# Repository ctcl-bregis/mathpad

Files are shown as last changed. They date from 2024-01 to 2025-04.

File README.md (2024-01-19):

# MathPad "Fort Myers"

MathPad was an idea to recreate HP's CalcPad device with modern components and design. The codename "Fort Myers" was chosen because the entire project was designed during the business trip to the Fort Myers area for work in Fort Myers Beach. The device was developed with the idea of that it would be used with the Xactimate estimating software.

The project was the first of CTCL's circuit design projects to reach the assembly stage; PCB and components ordered and received.

The project was likely abandoned in December 2022 due to the lack of equipment and skills required to solder the tiny, delicate components. The project was officially canceled on January 19, 2024 after the introduction of an off-the-shelf product, the Logitech G600 MMO mouse into my workflow in January 2023. This project was made with the idea of necessity as I was expected to start having to use Xactimate after the conclusion of the business trip.

On January 19, 2024, I released whatever work I had done for the project. The existing components ordered may be reused for other projects.

## Files
Included in the "hw" directory is all of the hardware files exported from EasyEDA.

No firmware has been developed for the device

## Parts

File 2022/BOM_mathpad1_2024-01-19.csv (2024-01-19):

ID | Name | Designator | Footprint | Quantity | Manufacturer Part | Manufacturer | Supplier | Supplier Part | Price
1 | 1uF | C1,C4,C5,C6,C7 | C0603 | 5 | CL10B105KO8NNNC | Samsung Electro-Mechanics | LCSC | C59782 | 0.004
2 | 4.7uF | C2,C3,C9 | C1206 | 3 | CL31B475KBHNNNE | Samsung Electro-Mechanics | LCSC | C51205 | 0.032
3 | 100nF | C8,C10,C11,C12,C13,C14,C15,C16 | C0603 | 8 | CL10B104KB8NNNC | Samsung Electro-Mechanics | LCSC | C1591 | 0.003
4 | 1N4148TR-C84412 | D1,D2,D3,D4,D5,D6,D7,D8,D9,D10,D11,D12,D13,D14,D15,D16,D17,D18,D19,D20,D21,D22,D23,D24,D25,D26,D27,D28,D29 | DO-35_BD2.0-L4.2-P8.20-D0.5-RD | 29 | 1N4148TR | Vishay | LCSC | C84412 | 0.022
5 | 0.5K-AX-31PWB | FPC1 | FPC-SMD_31P-P0.50_HDGC_0.5K-AX-31PWB | 1 | 0.5K-AX-31PWB | HDGC | LCSC | C2911949 | 0.156
6 | DZ254R-11-03-63 | H1 | HDR-TH_3P-P2.54-V-M | 1 | DZ254R-11-03-63 | Dealon | LCSC | C2935909 | 0.017
8 | 10uH | L1 | IND-SMD_L5.0-W5.0_LQH5BPBXX | 1 | LQH5BPB100MT0L | Murata Electronics | LCSC | C521243 | 0.256
9 | 1M | R1 | R0603 | 1 | RC0603JR-071ML | YAGEO | LCSC | C107698 | 0.001
10 | 68K | R2 | R0603 | 1 | RC0603JR-0768KL | YAGEO | LCSC | C113301 | 0.001
11 | 910K | R3 | R0603 | 1 | RC0603JR-07910KL | YAGEO | LCSC | C141274 | 0.001
12 | 0 | R4,R5 | R0603 | 2 | RC0603JR-070RL | YAGEO | LCSC | C95177 | 0.001
13 | CPG151101D93 | SW1,SW2,SW3,SW4,SW5,SW6,SW7,SW8,SW9,SW10,SW11,SW12,SW13,SW14,SW15,SW16,SW17,SW18,SW19,SW20,SW21,SW22,SW23,SW24,SW25,SW26,SW27,SW28,SW29 | SW-TH_CPG151101D9X | 29 | CPG151101D93 | Kailh | LCSC | C400237 | 0.248
14 | RT9078-33GJ5 | U1,U5 | TSOT-23-5_L2.9-W1.6-P0.95-LS2.8-BR | 2 | RT9078-33GJ5 | Richtek Tech | LCSC | C110427 | 0.09
15 | STM32G0B1RCT6 | U2 | LQFP-64_L10.0-W10.0-P0.50-LS12.0-BL | 1 | STM32G0B1RCT6 | STMicroelectronics | LCSC | C3034735 | 3.834
16 | TLV61046ADBVR | U3 | SOT-23-6_L2.9-W1.6-P0.95-LS2.8-BL | 1 | TLV61046ADBVR | Texas Instruments | LCSC | C464815 | 0.423
17 | U241-041N-1BR85-1 | USB1 | USB-B-TH_U241-041N-1BR85-1 | 1 | U241-041N-1BR85-1 | XKB Enterprise | LCSC | C397338 | 0.129
18 | 8MHz | X1 | OSC-SMD_3P-L3.2-W1.3-P1.2-L | 1 | CSTNE8M00G55A000R0 | Murata Electronics | LCSC | C341523 | 0.208

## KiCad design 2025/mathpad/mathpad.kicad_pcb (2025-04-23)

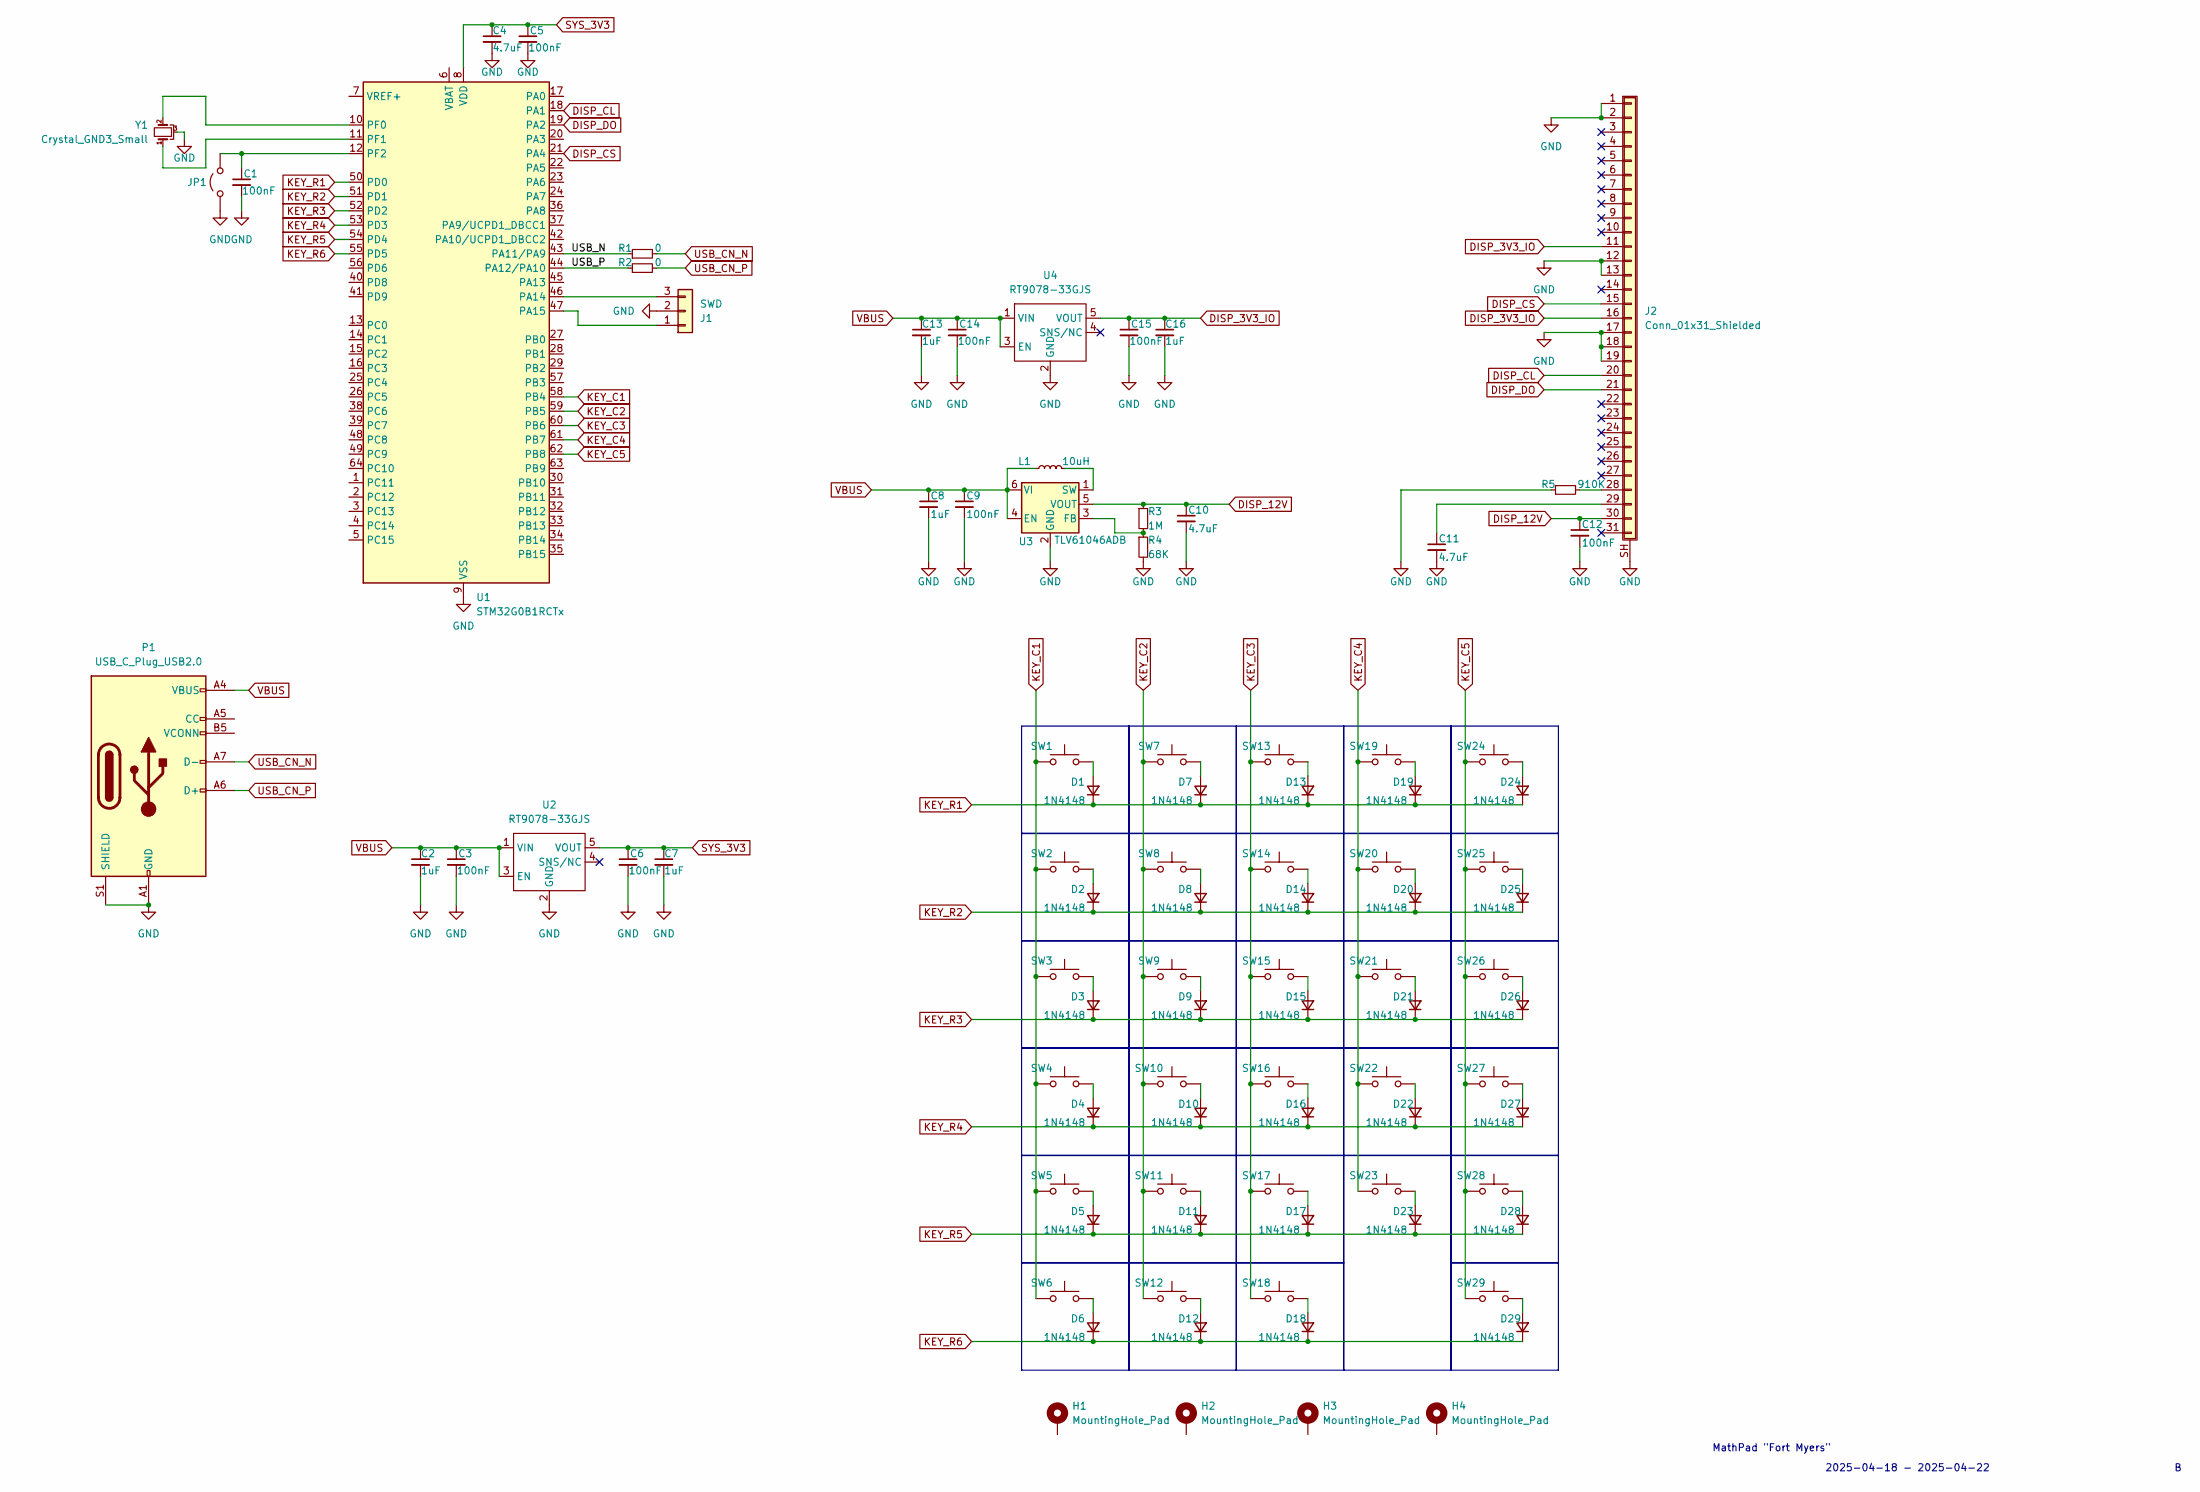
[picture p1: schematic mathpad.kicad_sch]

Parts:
C1, C3, C5, C6, C9, C12, C14, C15: 100nF; C_0603_1608Metric
C2, C7, C8, C13, C16: 1uF; C_0603_1608Metric
C4, C10, C11: 4.7uF; C_1206_3216Metric
D1, D2, D3, D4, D5, D6, D7, D8, D9, D10, D11, D12, D13, D14, D15, D16, D17, D18, D19, D20, D21, D22, D23, D24, D25, D26, D27, D28, D29: 1N4148; D_DO-35_SOD27_P7.62mm_Horizontal
H1, H2, H3, H4: MountingHole_Pad; MountingHole_2.2mm_M2_Pad
J1: SWD; PinHeader_1x03_P2.54mm_Vertical
J2: Conn_01x31_Shielded; TE_3-1734839-1_1x31-1MP_P0.5mm_Horizontal
JP1: Jumper_2_Open; SolderJumper-2_P1.3mm_Open_Pad1.0x1.5mm
L1: 10uH; L_Taiyo-Yuden_MD-5050
P1: USB_C_Plug_USB2.0; USB_C_Receptacle_G-Switch_GT-USB-7010ASV
R1, R2: 0; R_0603_1608Metric
R3: 1M; R_0603_1608Metric
R4: 68K; R_0603_1608Metric
R5: 910K; R_0603_1608Metric
SW1, SW2, SW3, SW4, SW5, SW6, SW7, SW8, SW9, SW10, SW11, SW12, SW13, SW14, SW15, SW16, SW17, SW18, SW19, SW20, SW21, SW22, SW23, SW24, SW25, SW26, SW27, SW28, SW29: SW_Push; SW_Cherry_MX_1.00u_PCB
U1: STM32G0B1RCTx; LQFP-64_10x10mm_P0.5mm
U2, U4: RT9078-33GJS; TSOT-23-5
U3: TLV61046ADB; SOT-23-6
Y1: Crystal_GND3_Small; Resonator_SMD_Murata_CSTCR_4.5x2x1.15mm

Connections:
/USB_N: R1.1, U1.43 (PA11/PA9)
/USB_P: R2.1, U1.44 (PA12/PA10)
DISP_3V3_IO: C15.1, C16.1, J2.11, J2.16, U4.5 (VOUT)
DISP_12V: C10.1, C12.1, J2.30, R3.1, U3.5 (VOUT)
DISP_CL: J2.20, U1.18 (PA1)
DISP_CS: J2.15, U1.21 (PA4)
DISP_DO: J2.21, U1.19 (PA2)
GND: C1.2, C2.2, C3.2, C4.2, C5.2, C6.2, C7.2, C8.2, C9.2, C10.2, C11.2, C12.2, C13.2, C14.2, C15.2, C16.2, J1.2, J2.1, J2.2, J2.12, J2.13, J2.17, J2.18, J2.19, J2.SH (Shield), JP1.2 (B), P1.A1 (GND), P1.A12 (GND), P1.B1 (GND), P1.B12 (GND), P1.S1 (SHIELD), R4.2, R5.1, U1.9 (VSS), U2.2 (GND), U3.2 (GND), U4.2 (GND), Y1.3
KEY_C1: SW1.1, SW2.1, SW3.1, SW4.1, SW5.1, SW6.1, U1.58 (PB4)
KEY_C2: SW7.1, SW8.1, SW9.1, SW10.1, SW11.1, SW12.1, U1.59 (PB5)
KEY_C3: SW13.1, SW14.1, SW15.1, SW16.1, SW17.1, SW18.1, U1.60 (PB6)
KEY_C4: SW19.1, SW20.1, SW21.1, SW22.1, SW23.1, U1.61 (PB7)
KEY_C5: SW24.1, SW25.1, SW26.1, SW27.1, SW28.1, SW29.1, U1.62 (PB8)
KEY_R1: D1.1 (K), D7.1 (K), D13.1 (K), D19.1 (K), D24.1 (K), U1.50 (PD0)
KEY_R2: D2.1 (K), D8.1 (K), D14.1 (K), D20.1 (K), D25.1 (K), U1.51 (PD1)
KEY_R3: D3.1 (K), D9.1 (K), D15.1 (K), D21.1 (K), D26.1 (K), U1.52 (PD2)
KEY_R4: D4.1 (K), D10.1 (K), D16.1 (K), D22.1 (K), D27.1 (K), U1.53 (PD3)
KEY_R5: D5.1 (K), D11.1 (K), D17.1 (K), D23.1 (K), D28.1 (K), U1.54 (PD4)
KEY_R6: D6.1 (K), D12.1 (K), D18.1 (K), D29.1 (K), U1.55 (PD5)
unnamed: D1.2 (A), SW1.2
unnamed: D2.2 (A), SW2.2
unnamed: D3.2 (A), SW3.2
unnamed: D4.2 (A), SW4.2
unnamed: D5.2 (A), SW5.2
unnamed: D6.2 (A), SW6.2
unnamed: D7.2 (A), SW7.2
unnamed: D8.2 (A), SW8.2
unnamed: D9.2 (A), SW9.2
unnamed: D10.2 (A), SW10.2
unnamed: D11.2 (A), SW11.2
unnamed: D12.2 (A), SW12.2
unnamed: D13.2 (A), SW13.2
unnamed: D14.2 (A), SW14.2
unnamed: D15.2 (A), SW15.2
unnamed: D16.2 (A), SW16.2
unnamed: D17.2 (A), SW17.2
unnamed: D18.2 (A), SW18.2
unnamed: D19.2 (A), SW19.2
unnamed: D20.2 (A), SW20.2
unnamed: D21.2 (A), SW21.2
unnamed: D22.2 (A), SW22.2
unnamed: D23.2 (A), SW23.2
unnamed: D24.2 (A), SW24.2
unnamed: D25.2 (A), SW25.2
unnamed: D26.2 (A), SW26.2
unnamed: D27.2 (A), SW27.2
unnamed: D28.2 (A), SW28.2
unnamed: D29.2 (A), SW29.2
unnamed: J1.1, U1.47 (PA15)
unnamed: J1.3, U1.46 (PA14)
unnamed: J2.28, R5.2
unnamed: C11.1, J2.29
unnamed: C1.1, JP1.1 (A), U1.12 (PF2)
unnamed: U1.10 (PF0), Y1.2
unnamed: U1.11 (PF1), Y1.1
unnamed: R3.2, R4.1, U3.3 (FB)
unnamed: L1.2, U3.1 (SW)
SYS_3V3: C4.1, C5.1, C6.1, C7.1, U1.8 (VDD), U2.5 (VOUT)
USB_CN_N: P1.A7 (D-), R1.2
USB_CN_P: P1.A6 (D+), R2.2
VBUS: C2.1, C3.1, C8.1, C9.1, C13.1, C14.1, L1.1, P1.A4 (VBUS), P1.A9 (VBUS), P1.B4 (VBUS), P1.B9 (VBUS), U2.1 (VIN), U2.3 (EN), U3.4 (EN), U3.6 (VI), U4.1 (VIN), U4.3 (EN)

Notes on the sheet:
MathPad "Fort Myers"
2025-04-18 - 2025-04-22

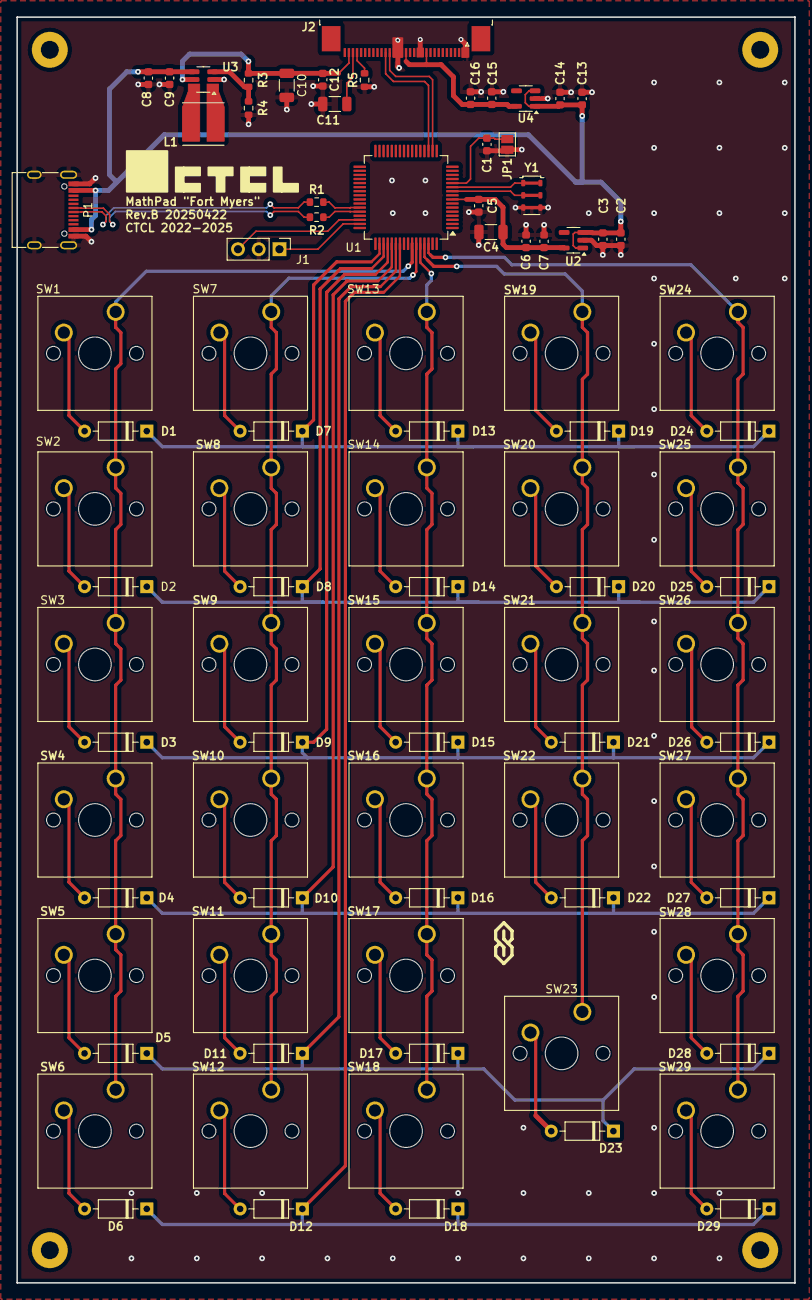
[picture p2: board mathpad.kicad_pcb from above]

Board: 4 copper layers, 95.2 x 155.0 mm, 93 parts (0 on the bottom side), 61 nets.
